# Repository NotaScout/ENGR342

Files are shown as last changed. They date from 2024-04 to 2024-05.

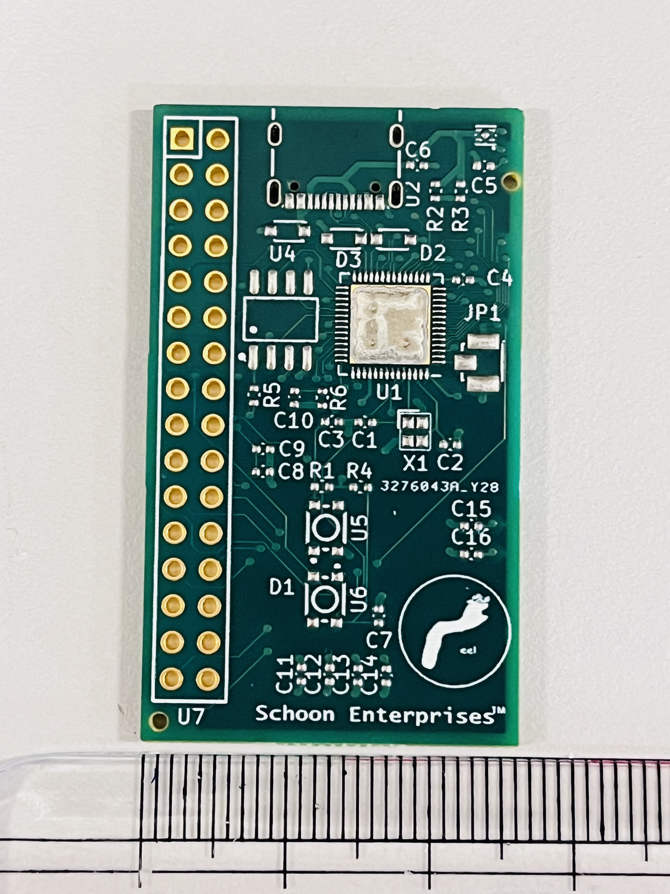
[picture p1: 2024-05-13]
Picture/IMG_0954.jpg

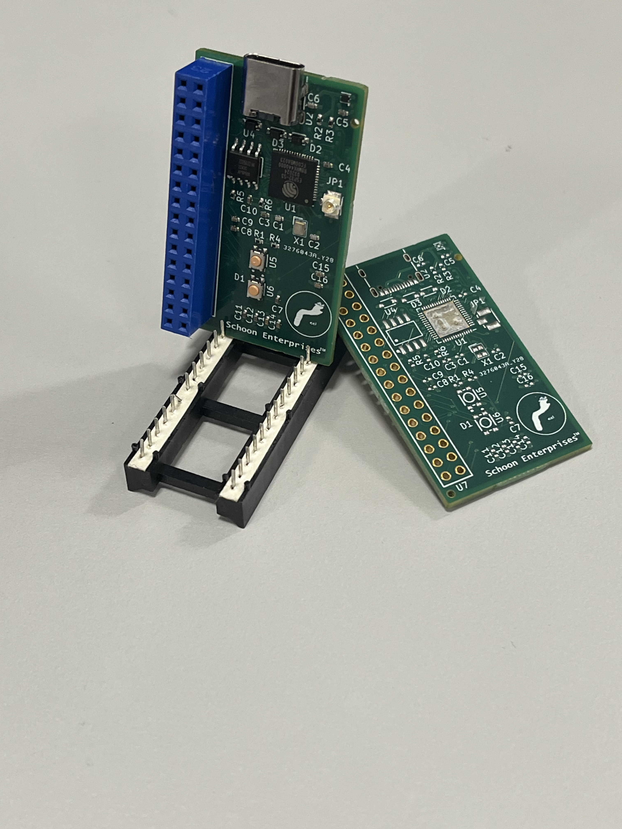
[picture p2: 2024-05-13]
Picture/IMG_0949.jpg

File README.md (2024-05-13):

// ENGR 342

// It be a ESP-32 S2 based Microcontroller with Wifi-antenna, Innit?







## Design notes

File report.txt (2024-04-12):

Info: Processing symbol 'U1:Package_DFN_QFN:QFN-56-1EP_7x7mm_P0.4mm_EP5.6x5.6mm'.
Added U1 (footprint 'Package_DFN_QFN:QFN-56-1EP_7x7mm_P0.4mm_EP5.6x5.6mm').
Changed REF** reference designator to U1.
Changed U1 value from QFN-56-1EP_7x7mm_P0.4mm_EP5.6x5.6mm to ESP32-S3.
Updated U1 symbol association from  to /3021fe6b-de7b-45d1-be0a-b81a54ababc5.
Updated U1 properties.
Add net unconnected-(U1-LNA_IN/RF-Pad1).
Connected U1 pin 1 to unconnected-(U1-LNA_IN/RF-Pad1).
Add net VDD3P3.
Connected U1 pin 2 to VDD3P3.
Connected U1 pin 3 to VDD3P3.
Add net unconnected-(U1-CHIP_PU/RESET-Pad4).
Connected U1 pin 4 to unconnected-(U1-CHIP_PU/RESET-Pad4).
Add net unconnected-(U1-GPIO0/BOOT-Pad5).
Connected U1 pin 5 to unconnected-(U1-GPIO0/BOOT-Pad5).
Add net unconnected-(U1-GPIO1/ADC1_CH0-Pad6).
Connected U1 pin 6 to unconnected-(U1-GPIO1/ADC1_CH0-Pad6).
Add net unconnected-(U1-GPIO2/ADC1_CH1-Pad7).
Connected U1 pin 7 to unconnected-(U1-GPIO2/ADC1_CH1-Pad7).
Add net unconnected-(U1-GPIO3/ADC1_CH2-Pad8).
Connected U1 pin 8 to unconnected-(U1-GPIO3/ADC1_CH2-Pad8).
Add net unconnected-(U1-GPIO4/ADC1_CH3-Pad9).
Connected U1 pin 9 to unconnected-(U1-GPIO4/ADC1_CH3-Pad9).
Add net unconnected-(U1-GPIO5/ADC1_CH4-Pad10).
Connected U1 pin 10 to unconnected-(U1-GPIO5/ADC1_CH4-Pad10).
Add net unconnected-(U1-GPIO6/ADC1_CH5-Pad11).
Connected U1 pin 11 to unconnected-(U1-GPIO6/ADC1_CH5-Pad11).
Add net unconnected-(U1-GPIO7/ADC1_CH6-Pad12).
Connected U1 pin 12 to unconnected-(U1-GPIO7/ADC1_CH6-Pad12).
Add net unconnected-(U1-GPIO8/ADC1_CH7-Pad13).
Connected U1 pin 13 to unconnected-(U1-GPIO8/ADC1_CH7-Pad13).
Add net unconnected-(U1-GPIO9/ADC1_CH8-Pad14).
Connected U1 pin 14 to unconnected-(U1-GPIO9/ADC1_CH8-Pad14).
Add net unconnected-(U1-GPIO10/ADC1_CH9-Pad15).
Connected U1 pin 15 to unconnected-(U1-GPIO10/ADC1_CH9-Pad15).
Add net unconnected-(U1-GPIO11/ADC2_CH0-Pad16).
Connected U1 pin 16 to unconnected-(U1-GPIO11/ADC2_CH0-Pad16).
Add net unconnected-(U1-GPIO12/ADC2_CH1-Pad17).
Connected U1 pin 17 to unconnected-(U1-GPIO12/ADC2_CH1-Pad17).
Add net unconnected-(U1-GPIO13/ADC2_CH2-Pad18).
Connected U1 pin 18 to unconnected-(U1-GPIO13/ADC2_CH2-Pad18).
Add net unconnected-(U1-GPIO14/ADC2_CH3-Pad19).
Connected U1 pin 19 to unconnected-(U1-GPIO14/ADC2_CH3-Pad19).
Add net unconnected-(U1-VDD3P3_RTC-Pad20).
Connected U1 pin 20 to unconnected-(U1-VDD3P3_RTC-Pad20).
Add net unconnected-(U1-GPIO15/ADC2_CH4/XTAL_32K_P-Pad21).
Connected U1 pin 21 to unconnected-(U1-GPIO15/ADC2_CH4/XTAL_32K_P-Pad21).
Add net unconnected-(U1-GPIO16/ADC2_CH5/XTAL_32K_N-Pad22).
Connected U1 pin 22 to unconnected-(U1-GPIO16/ADC2_CH5/XTAL_32K_N-Pad22).
Add net unconnected-(U1-GPIO17/ADC2_CH6-Pad23).
Connected U1 pin 23 to unconnected-(U1-GPIO17/ADC2_CH6-Pad23).
Add net unconnected-(U1-GPIO18/ADC2_CH7-Pad24).
Connected U1 pin 24 to unconnected-(U1-GPIO18/ADC2_CH7-Pad24).
Add net unconnected-(U1-GPIO19/USB_D-/ADC2_CH8-Pad25).
Connected U1 pin 25 to unconnected-(U1-GPIO19/USB_D-/ADC2_CH8-Pad25).
Add net unconnected-(U1-GPIO20/USB_D+/ADC2_CH9-Pad26).
Connected U1 pin 26 to unconnected-(U1-GPIO20/USB_D+/ADC2_CH9-Pad26).
Add net unconnected-(U1-GPIO21-Pad27).
Connected U1 pin 27 to unconnected-(U1-GPIO21-Pad27).
Add net unconnected-(U1-SPI_CS1/GPIO26-Pad28).
Connected U1 pin 28 to unconnected-(U1-SPI_CS1/GPIO26-Pad28).
Add net unconnected-(U1-VDD_SPI-Pad29).
Connected U1 pin 29 to unconnected-(U1-VDD_SPI-Pad29).
Add net unconnected-(U1-SPIHD/GPIO27-Pad30).
Connected U1 pin 30 to unconnected-(U1-SPIHD/GPIO27-Pad30).
Add net unconnected-(U1-SPIWP/GPIO28-Pad31).
Connected U1 pin 31 to unconnected-(U1-SPIWP/GPIO28-Pad31).
Add net unconnected-(U1-SPICS0/GPIO29-Pad32).
Connected U1 pin 32 to unconnected-(U1-SPICS0/GPIO29-Pad32).
Add net unconnected-(U1-SPICLK/GPIO30-Pad33).
Connected U1 pin 33 to unconnected-(U1-SPICLK/GPIO30-Pad33).
Add net unconnected-(U1-SPIQ/GPIO31-Pad34).
Connected U1 pin 34 to unconnected-(U1-SPIQ/GPIO31-Pad34).
Add net unconnected-(U1-SPID/GPIO32-Pad35).
Connected U1 pin 35 to unconnected-(U1-SPID/GPIO32-Pad35).
Add net unconnected-(U1-SPICLK_N/GPIO48-Pad36).
Connected U1 pin 36 to unconnected-(U1-SPICLK_N/GPIO48-Pad36).
Add net unconnected-(U1-SPICLK_P/GPIO47-Pad37).
Connected U1 pin 37 to unconnected-(U1-SPICLK_P/GPIO47-Pad37).
Add net unconnected-(U1-GPIO33-Pad38).
Connected U1 pin 38 to unconnected-(U1-GPIO33-Pad38).
Add net unconnected-(U1-GPIO34-Pad39).
Connected U1 pin 39 to unconnected-(U1-GPIO34-Pad39).
Add net unconnected-(U1-GPIO35-Pad40).
Connected U1 pin 40 to unconnected-(U1-GPIO35-Pad40).
Add net unconnected-(U1-GPIO36-Pad41).
Connected U1 pin 41 to unconnected-(U1-GPIO36-Pad41).
Add net unconnected-(U1-GPIO37-Pad42).
Connected U1 pin 42 to unconnected-(U1-GPIO37-Pad42).
Add net unconnected-(U1-GPIO38-Pad43).
Connected U1 pin 43 to unconnected-(U1-GPIO38-Pad43).
Add net unconnected-(U1-MTCK/JTAG/GPIO39-Pad44).
Connected U1 pin 44 to unconnected-(U1-MTCK/JTAG/GPIO39-Pad44).
Add net unconnected-(U1-MTDO/JTAG/GPIO40-Pad45).
Connected U1 pin 45 to unconnected-(U1-MTDO/JTAG/GPIO40-Pad45).
Add net unconnected-(U1-VDD3P3_CPU-Pad46).
Connected U1 pin 46 to unconnected-(U1-VDD3P3_CPU-Pad46).
Add net unconnected-(U1-MTDI/JTAG/GPIO41-Pad47).
Connected U1 pin 47 to unconnected-(U1-MTDI/JTAG/GPIO41-Pad47).
Add net unconnected-(U1-MTMS/JTAG/GPIO42-Pad48).
Connected U1 pin 48 to unconnected-(U1-MTMS/JTAG/GPIO42-Pad48).
Add net unconnected-(U1-U0TXD/PROG/GPIO43-Pad49).
Connected U1 pin 49 to unconnected-(U1-U0TXD/PROG/GPIO43-Pad49).
Add net unconnected-(U1-U0RXD/PROG/GPIO44-Pad50).
Connected U1 pin 50 to unconnected-(U1-U0RXD/PROG/GPIO44-Pad50).
Add net unconnected-(U1-GPIO45-Pad51).
Connected U1 pin 51 to unconnected-(U1-GPIO45-Pad51).
Add net unconnected-(U1-GPIO46-Pad52).
Connected U1 pin 52 to unconnected-(U1-GPIO46-Pad52).
Add net unconnected-(U1-XTAL_N-Pad53).
Connected U1 pin 53 to unconnected-(U1-XTAL_N-Pad53).
Add net unconnected-(U1-XTAL_P-Pad54).
Connected U1 pin 54 to unconnected-(U1-XTAL_P-Pad54).
Add net Net-(U1-VDDA-Pad55).
Connected U1 pin 55 to Net-(U1-VDDA-Pad55).
Connected U1 pin 56 to Net-(U1-VDDA-Pad55).
Add net unconnected-(U1-GND-Pad57).
Connected U1 pin 57 to unconnected-(U1-GND-Pad57).

Info: Total warnings: 0, errors: 0.

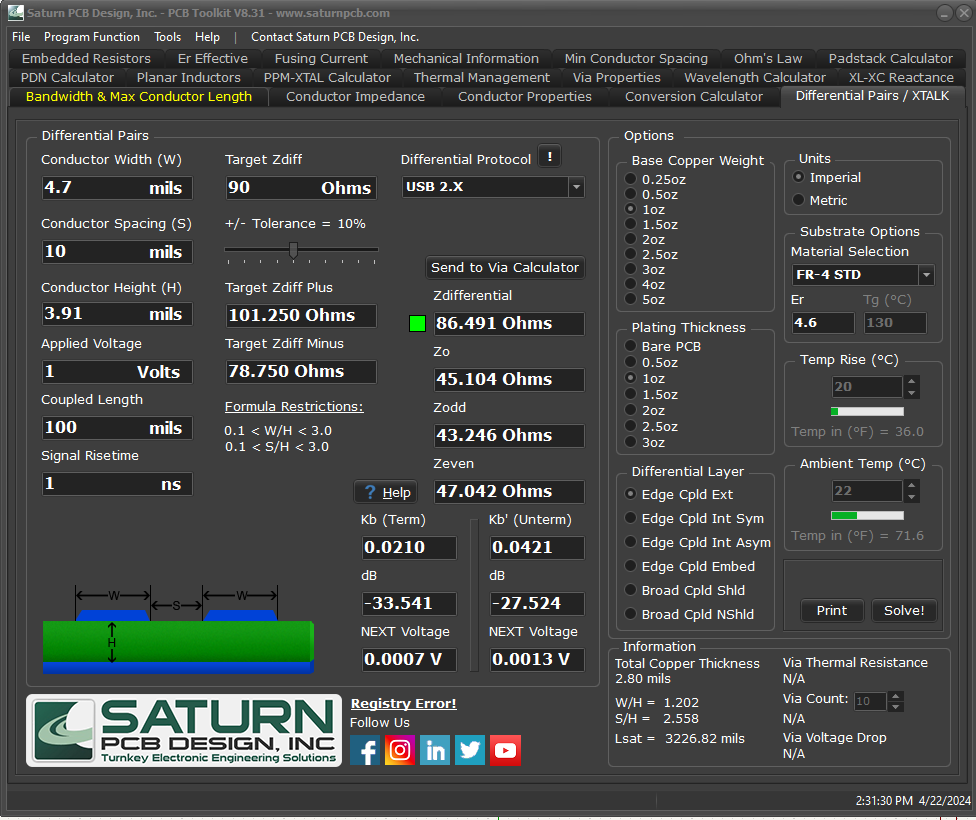
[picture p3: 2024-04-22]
notes/USB_ZMATCH.png

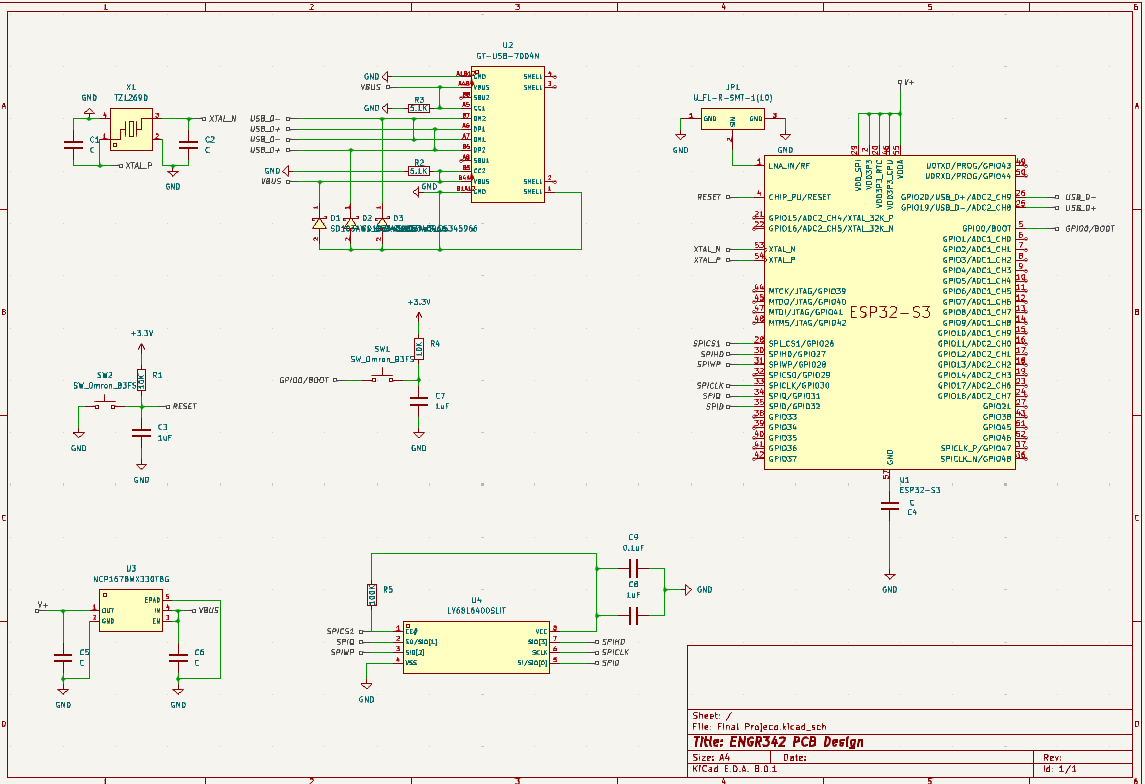
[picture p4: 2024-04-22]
prep/PCB_after_revision.png

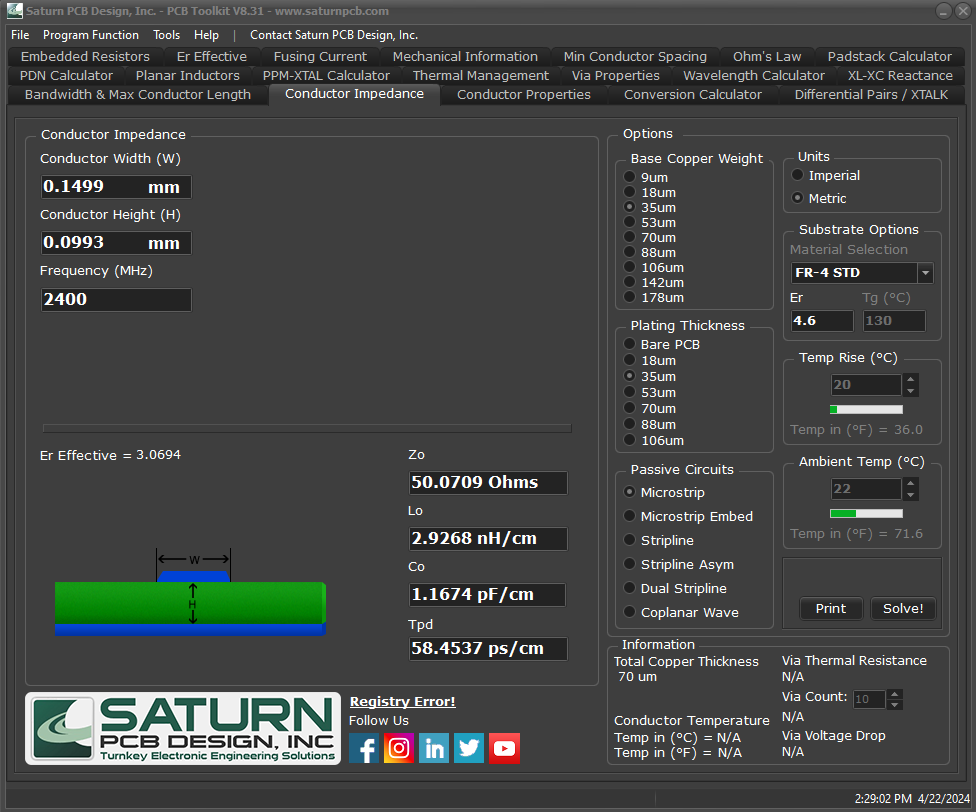
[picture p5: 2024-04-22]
notes/Non-USB_ZMatch.png

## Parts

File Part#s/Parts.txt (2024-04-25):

C

1uF - C29266
0.1uF - C307331
10uF -
13pF - C161528

R

5.1k - C14677
10k - C25744
100k - C25741

Cosc cap calc:
https://forum.digikey.com/t/crystal-oscillator-load-cap-selection/1915
example
So to use the above formula
( 2 x Load Capacitance of Crystal ) - Stray Capacitance

( 2 * 9pF ) - 5pf = 13pF

mine (for our Cosc its also 9, so we can just use a 12p)
( 2 * 9pF ) - 5pf = 13pF

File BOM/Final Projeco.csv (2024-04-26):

Reference | Value | Datasheet | Footprint | Qty | DNP | LCSC
C1,C2 | 13pF | ~ | Capacitor_SMD:C_0402_1005Metric | 2 |  | C161528
C3,C4,C5,C6,C7,C8,C10,C11,C12 | 1uF | ~ | Capacitor_SMD:C_0402_1005Metric | 9 |  | C29266
C9,C13,C14,C15,C16 | 0.1uF | ~ | Capacitor_SMD:C_0402_1005Metric | 5 |  | C307331
D1,D2,D3 | SD103AWS_C5345966 | https://img.jlc.com/pdf/applyPasteComponent/2021-04-20/390362A/6f25ed4711644192b46323c806fc55eb/1020-007045-BAP70-03.pdf | jlc:SOD-323_L1.7-W1.3-LS2.5-RD | 3 |  | C5345966
JP1 | U_FL-R-SMT-1(10) | https://item.szlcsc.com/89552.html | jlc:ANT-SMD_UFL-R-SMT-1-10 | 1 |  | C88373
R1,R4 | 10K | ~ | Resistor_SMD:R_0402_1005Metric | 2 |  | C25744
R2,R3 | 5.1K | ~ | Resistor_SMD:R_0402_1005Metric | 2 |  | C14677
R5 | 100K | ~ | Resistor_SMD:R_0402_1005Metric | 1 |  | C25741
R6 | 442k | ~ | Resistor_SMD:R_0402_1005Metric | 1 |  | C3016035
U1 | ESP32-S3 | https://www.espressif.com/sites/default/files/documentation/esp32-s3_datasheet_en.pdf | Package_DFN_QFN:QFN-56-1EP_7x7mm_P0.4mm_EP5.6x5.6mm | 1 |  | C2913194
U2 | GT-USB-7004N | https://atta.szlcsc.com/upload/public/pdf/source/20210507/C2686968_A2C7AC8037FA641926B2358B7DAFD325.pdf | jlc:USB-C-SMD_GT-USB-7004 | 1 |  | C2848971
U3 | NCP167BMX330TBG | https://item.szlcsc.com/196276.html | jlc:XDFN-4_L1.0-W1.0-P0.65-BL-EP | 1 |  | C892227
U4 | ZD25Q32CTIGT | https://item.szlcsc.com/383602.html | jlc:SOP-8_L4.9-W3.9-P1.27-LS6.0-BL | 1 |  | C261881
U5,U6 | PTS830GG140SMTRLFS | https://atta.szlcsc.com/upload/public/pdf/source/20220328/BDDB210D3ABA2FDDFE99547E02ACE199.pdf | jlc:KEY-SMD_4P-L3.1-W2.6_PTS830GG140SMTRLFS | 2 |  | C221902
U7 | 220S-2*16P_H=8_5MM_Ytype_L=3_0MM_PBT | https://item.szlcsc.com/2776437.html?ref=editor&logined=true | jlc:HDR-TH_32P-P2.54-V-F-R2-C16-S2.54 | 1 |  | C115248
X1 | TZ1269D | https://atta.szlcsc.com/upload/public/pdf/source/20210612/25E10314463341ECFDA871AE575B9E16.pdf | jlc:CRYSTAL-SMD_4P-L2.0-W1.6-BL-A | 1 |  | C501798

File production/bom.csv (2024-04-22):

Designator | Footprint | Quantity | Value | LCSC Part #
C1, C2, C4, C5, C6 | 0402 | 5 | C
C3, C7, C8 | 0402 | 3 | 1uF
C9 | 0402 | 1 | 0.1uF
D1, D2, D3 | SOD-323_L1.7-W1.3-LS2.5-RD | 3 | SD103AWS_C5345966 | C5345966
JP1 | ANT-SMD_UFL-R-SMT-1-10 | 1 | U_FL-R-SMT-1(10) | C88373
R1, R4 | 0402 | 2 | 10K
R2, R3 | 0402 | 2 | 5.1K
R5 | 0402 | 1 | 100K
U1 | QFN-56-1EP_7x7mm_P0.4mm_EP5.6x5.6mm | 1 | ESP32-S3 | C291392
U2 | USB-C-SMD_GT-USB-7004 | 1 | GT-USB-7004N | C2848971
U3 | XDFN-4_L1.0-W1.0-P0.65-BL-EP | 1 | NCP167BMX330TBG | C892227
U4 | SOP-8_L4.9-W3.9-P1.27-LS6.0-BL | 1 | LY68L6400SLIT | C261881
X1 | CRYSTAL-SMD_4P-L2.0-W1.6-BL-A | 1 | TZ1269D | C501798

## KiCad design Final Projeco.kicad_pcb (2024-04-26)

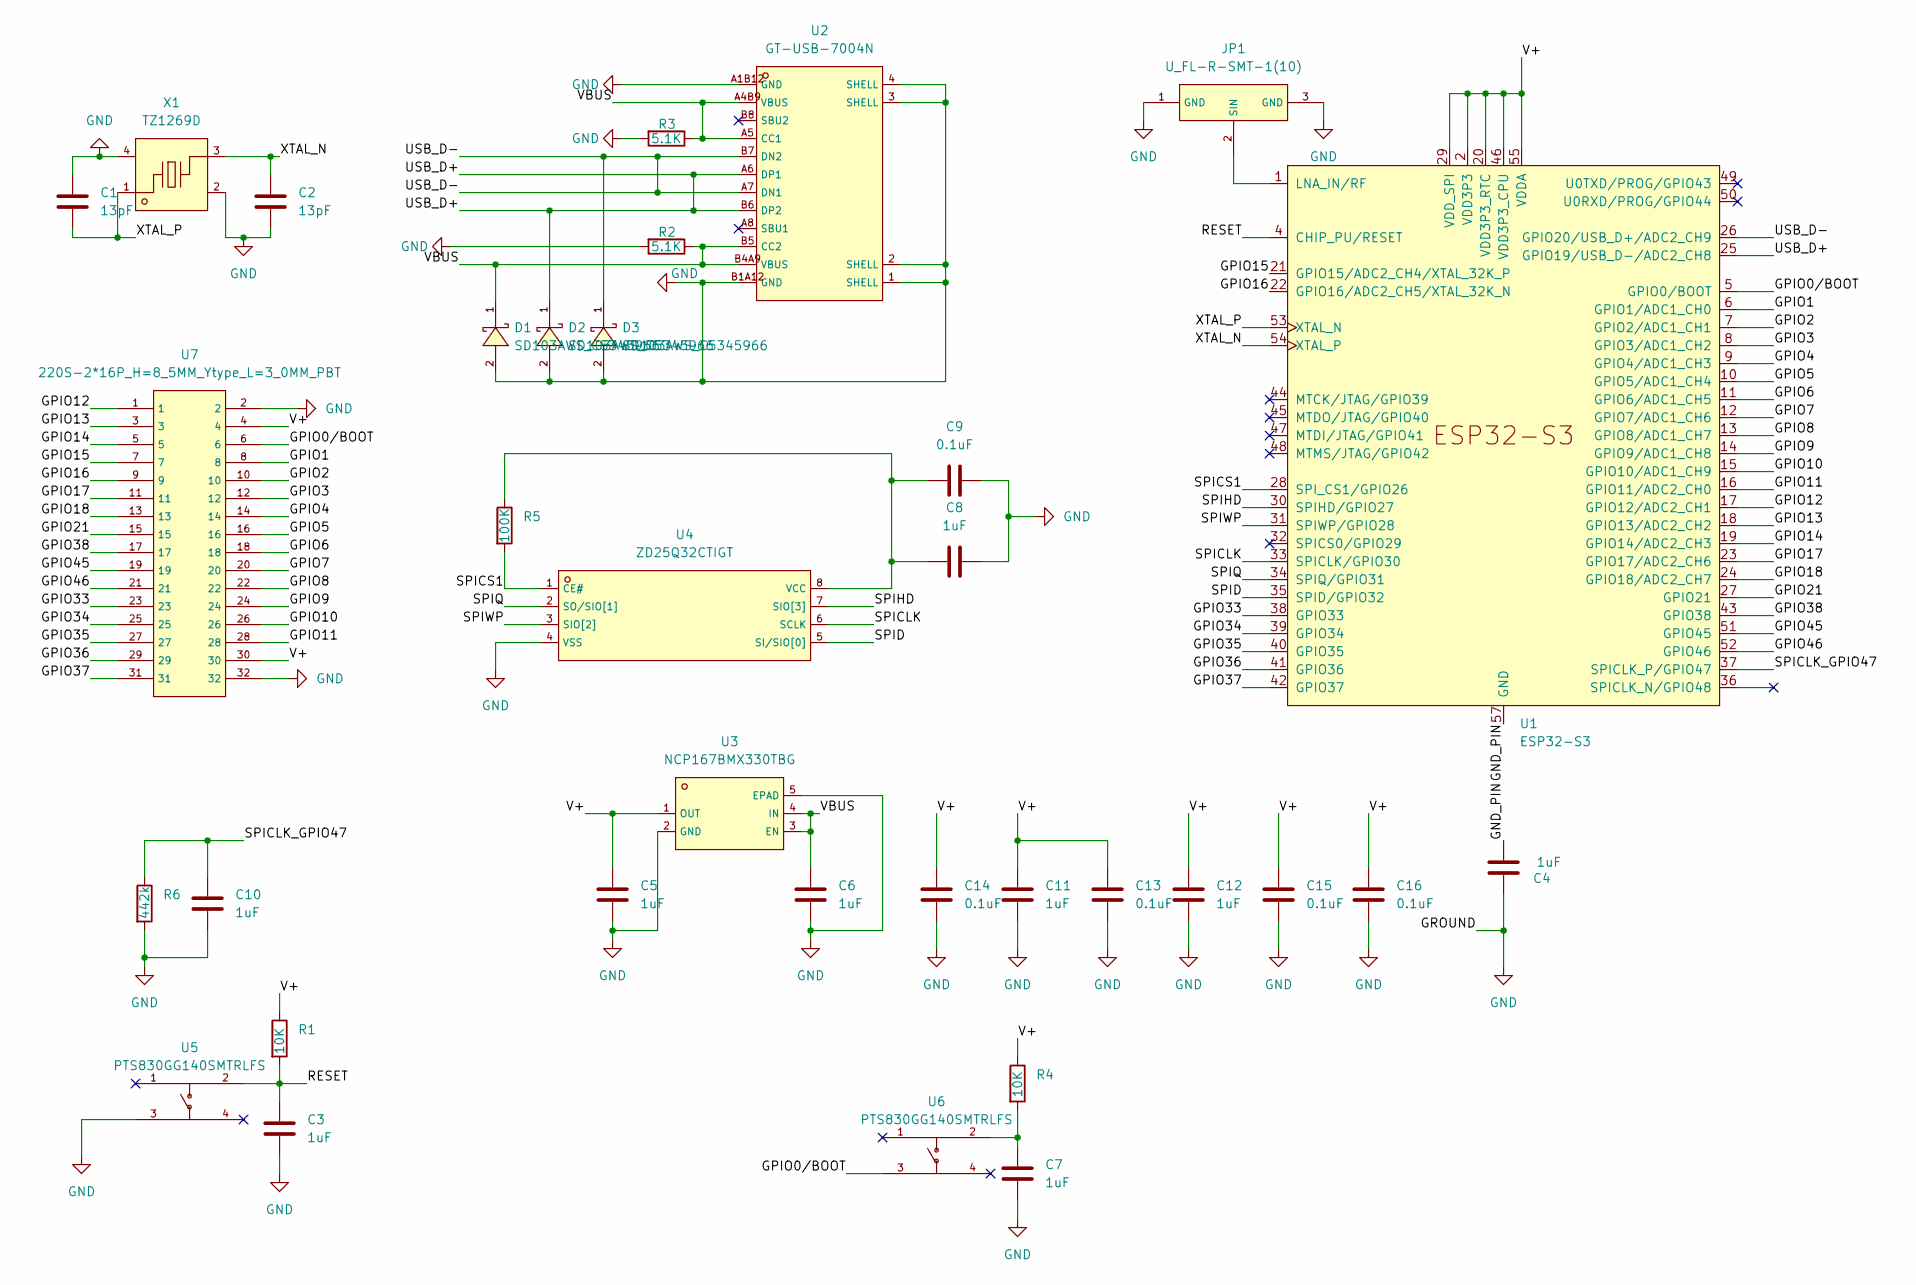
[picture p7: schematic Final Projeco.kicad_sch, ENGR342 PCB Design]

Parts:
C1, C2: 13pF; C_0402_1005Metric; LCSC C161528
C3, C4, C5, C6, C7, C8, C10, C11, C12: 1uF; C_0402_1005Metric; LCSC C29266
C9, C13, C14, C15, C16: 0.1uF; C_0402_1005Metric; LCSC C307331
D1, D2, D3: SD103AWS_C5345966; SOD-323_L1.7-W1.3-LS2.5-RD; LCSC C5345966
JP1: U_FL-R-SMT-1(10); ANT-SMD_UFL-R-SMT-1-10; LCSC C88373
R1, R4: 10K; R_0402_1005Metric; LCSC C25744
R2, R3: 5.1K; R_0402_1005Metric; LCSC C14677
R5: 100K; R_0402_1005Metric; LCSC C25741
R6: 442k; R_0402_1005Metric; LCSC C3016035
U1: ESP32-S3; QFN-56-1EP_7x7mm_P0.4mm_EP5.6x5.6mm; LCSC C2913194
U2: GT-USB-7004N; USB-C-SMD_GT-USB-7004; LCSC C2848971
U3: NCP167BMX330TBG; XDFN-4_L1.0-W1.0-P0.65-BL-EP; LCSC C892227
U4: ZD25Q32CTIGT; SOP-8_L4.9-W3.9-P1.27-LS6.0-BL; LCSC C261881
U5, U6: PTS830GG140SMTRLFS; KEY-SMD_4P-L3.1-W2.6_PTS830GG140SMTRLFS; LCSC C221902
U7: 220S-2*16P_H=8_5MM_Ytype_L=3_0MM_PBT; HDR-TH_32P-P2.54-V-F-R2-C16-S2.54; LCSC C115248
X1: TZ1269D; CRYSTAL-SMD_4P-L2.0-W1.6-BL-A; LCSC C501798

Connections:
/GND_PIN: C4.1, U1.57 (GND)
/GPIO0/BOOT: U1.5 (GPIO0/BOOT), U6.3, U7.6
/GPIO1: U1.6 (GPIO1/ADC1_CH0), U7.8
/GPIO2: U1.7 (GPIO2/ADC1_CH1), U7.10
/GPIO3: U1.8 (GPIO3/ADC1_CH2), U7.12
/GPIO4: U1.9 (GPIO4/ADC1_CH3), U7.14
/GPIO5: U1.10 (GPIO5/ADC1_CH4), U7.16
/GPIO6: U1.11 (GPIO6/ADC1_CH5), U7.18
/GPIO7: U1.12 (GPIO7/ADC1_CH6), U7.20
/GPIO8: U1.13 (GPIO8/ADC1_CH7), U7.22
/GPIO9: U1.14 (GPIO9/ADC1_CH8), U7.24
/GPIO10: U1.15 (GPIO10/ADC1_CH9), U7.26
/GPIO11: U1.16 (GPIO11/ADC2_CH0), U7.28
/GPIO12: U1.17 (GPIO12/ADC2_CH1), U7.1
/GPIO13: U1.18 (GPIO13/ADC2_CH2), U7.3
/GPIO14: U1.19 (GPIO14/ADC2_CH3), U7.5
/GPIO15: U1.21 (GPIO15/ADC2_CH4/XTAL_32K_P), U7.7
/GPIO16: U1.22 (GPIO16/ADC2_CH5/XTAL_32K_N), U7.9
/GPIO17: U1.23 (GPIO17/ADC2_CH6), U7.11
/GPIO18: U1.24 (GPIO18/ADC2_CH7), U7.13
/GPIO21: U1.27 (GPIO21), U7.15
/GPIO33: U1.38 (GPIO33), U7.23
/GPIO34: U1.39 (GPIO34), U7.25
/GPIO35: U1.40 (GPIO35), U7.27
/GPIO36: U1.41 (GPIO36), U7.29
/GPIO37: U1.42 (GPIO37), U7.31
/GPIO38: U1.43 (GPIO38), U7.17
/GPIO45: U1.51 (GPIO45), U7.19
/GPIO46: U1.52 (GPIO46), U7.21
/RESET: C3.1, R1.2, U1.4 (CHIP_PU/RESET), U5.2
/SPICLK: U1.33 (SPICLK/GPIO30), U4.6 (SCLK)
/SPICLK_GPIO47: C10.1, R6.1, U1.37 (SPICLK_P/GPIO47)
/SPICS1: R5.2, U1.28 (SPI_CS1/GPIO26), U4.1 (CE#)
/SPID: U1.35 (SPID/GPIO32), U4.5 (SI/SIO[0])
/SPIHD: U1.30 (SPIHD/GPIO27), U4.7 (SIO[3])
/SPIQ: U1.34 (SPIQ/GPIO31), U4.2 (SO/SIO[1])
/SPIWP: U1.31 (SPIWP/GPIO28), U4.3 (SIO[2])
/USB_D+: D2.1 (K), U1.25 (GPIO19/USB_D-/ADC2_CH8), U2.A6 (DP1), U2.B6 (DP2)
/USB_D-: D3.1 (K), U1.26 (GPIO20/USB_D+/ADC2_CH9), U2.A7 (DN1), U2.B7 (DN2)
/VBUS: C6.1, D1.1 (K), R2.1, R3.1, U2.A4B9 (VBUS), U2.A5 (CC1), U2.B4A9 (VBUS), U2.B5 (CC2), U3.3 (EN), U3.4 (IN)
/XTAL_N: C2.1, U1.54 (XTAL_P), X1.3
/XTAL_P: C1.2, U1.53 (XTAL_N), X1.1
GND: C1.1, C2.2, C3.2, C4.2, C5.2, C6.2, C7.2, C8.2, C9.2, C10.2, C11.2, C12.2, C13.1, C14.1, C15.1, C16.1, D1.2 (A), D2.2 (A), D3.2 (A), JP1.1 (GND), JP1.3 (GND), R2.2, R3.2, R6.2, U2.1 (SHELL), U2.2 (SHELL), U2.3 (SHELL), U2.4 (SHELL), U2.A1B12 (GND), U2.B1A12 (GND), U3.2 (GND), U3.5 (EPAD), U4.4 (VSS), U5.3, U7.2, U7.32, X1.2 (GND), X1.4 (GND)
unnamed: C7.1, R4.2, U6.2
unnamed: JP1.2 (SIN), U1.1 (LNA_IN/RF)
unnamed: C8.1, C9.1, R5.1, U4.8 (VCC)
VDD3P3: C5.1, C11.1, C12.1, C13.2, C14.2, C15.2, C16.2, R1.1, R4.1, U1.2 (VDD3P3), U1.3 (VDD3P3), U1.20 (VDD3P3_RTC), U1.29 (VDD_SPI), U1.46 (VDD3P3_CPU), U1.55 (VDDA), U1.56 (VDDA), U3.1 (OUT), U7.4, U7.30

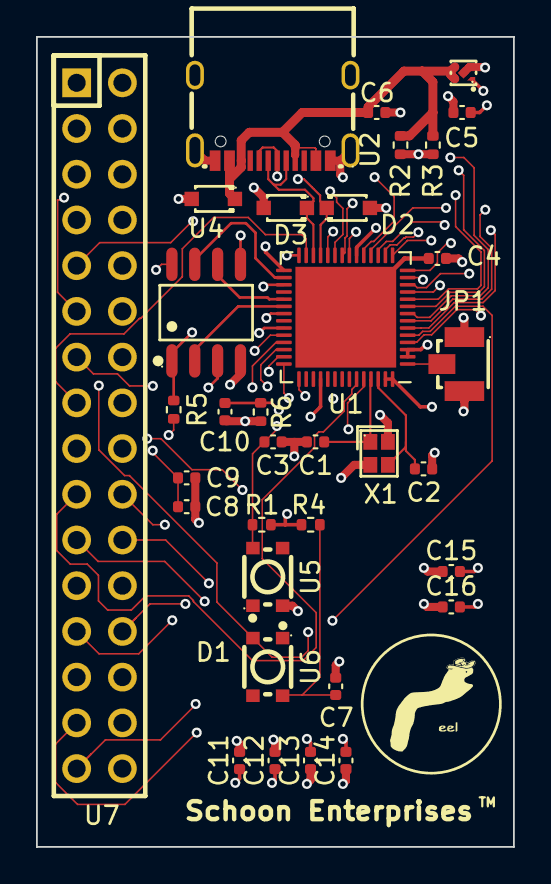
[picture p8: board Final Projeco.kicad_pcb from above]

Board: 6 copper layers, 26.5 x 45.0 mm, 34 parts (0 on the bottom side), 47 nets.

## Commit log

2024-04-12 -Added Project Files
    [ENGR342_Microcontroller_PCB.kicad_pcb, ENGR342_Microcontroller_PCB.kicad_sch, Final Projeco.kicad_pcb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]
2024-04-12 -Updated some parts -added datasheets for possible Antanneax -design is structurally complete... I think?
    [Final Projeco.kicad_sch]
2024-04-15 -Cleaned up schematic (Nets) -Added more Deditated wam
    [Final Projeco.csv, Final Projeco.kicad_sch]
2024-04-15 -USE IPEX 2.4 GHz Antenna
    [Final Projeco.kicad_pcb, Final Projeco.kicad_sch]
2024-04-22 Fixed all the traces to connect to each other :-|
    [ENGR342_Microcontroller_PCB.kicad_pcb, ENGR342_Microcontroller_PCB.kicad_sch, Final Projeco.csv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]
2024-04-22 Fixed some stuff
    -added diff pair net rules
    -added base net rules
    -added zmatch net rules
    [Final Projeco.kicad_pcb, Final Projeco.kicad_sch]
2024-04-24 Started Routing
    [Final Projeco.kicad_pcb, Final Projeco.kicad_sch]
2024-04-26 Final build init commit
    -No DRC errors,
    -All routed
    [Final Projeco.kicad_pcb]
2024-04-26 -Final Files Part II
    Generated BOM, CPL, & GBRs,
    TODO;
    -Remove RAM & all wires related
    [BOM.csv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]
2024-04-26 -Final Draft Submission mk2
    -Added bypass caps across 3.3 & GND to make signal less ripple-y
    -added component to replace SRAM chip:
    https://jlcpcb.com/partdetail/Zetta-ZD25Q32CTIGT/C3029778
    [Final Projeco-B_Cu.gbl, Final Projeco-B_Mask.gbs, Final Projeco-B_Paste.gbp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]
2024-05-13 -Picutre
    - + Added Pictures of printed boards.
2024-05-13 Addded depictions of our board
